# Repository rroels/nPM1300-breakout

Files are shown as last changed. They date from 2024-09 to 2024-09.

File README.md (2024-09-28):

# Nordic nPM1300 Breakout Board

> [!WARNING]
> The information and material (code, designs, files, ...) are provided "AS IS". We make no representation or warranty of any kind, express or implied, regarding the accuracy, adequacy, validity, reliability, availability, or completeness of any information or material. Use this at your own risk.

> [!WARNING]
> At the time of writing this PCB has not even been produced yet, and as such, it has not even been tested yet! Once it has been properly tested, I will confirm that everything works as expected.

## Introduction

This is a breakout board for the Nordic nPM1300 Power Management IC.

[https://www.nordicsemi.com/Products/nPM1300](https://www.nordicsemi.com/Products/nPM1300)

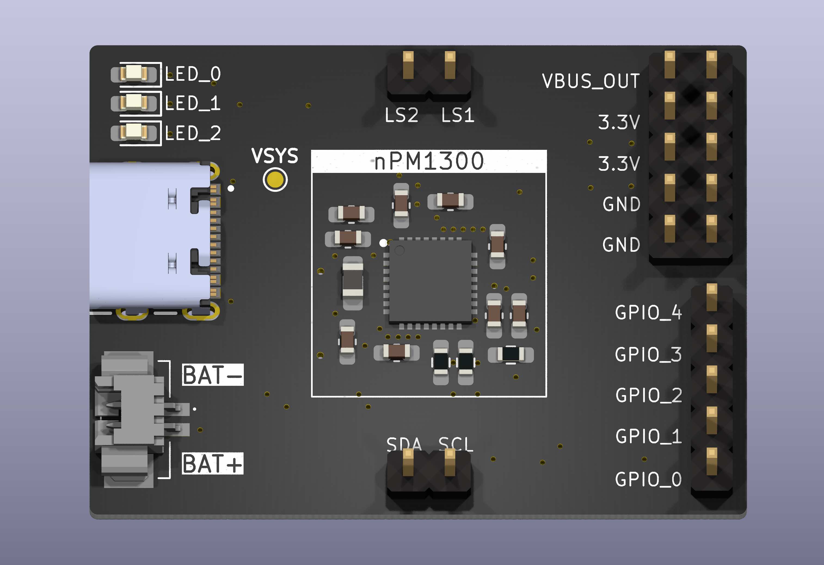
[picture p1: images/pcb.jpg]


## Change Log

* v1.0
  * Initial design 

## Design Considerations

In this design, the nPM1300 is configured like this:

* BUCK1 disabled
* BUCK2 enabled, for converting battery or USB input to 3.3V
* 2 load switches at 3.3V (LS1 and LS2)
* no LDO 
* 3 LEDs
* I2C interface

## Schematics 

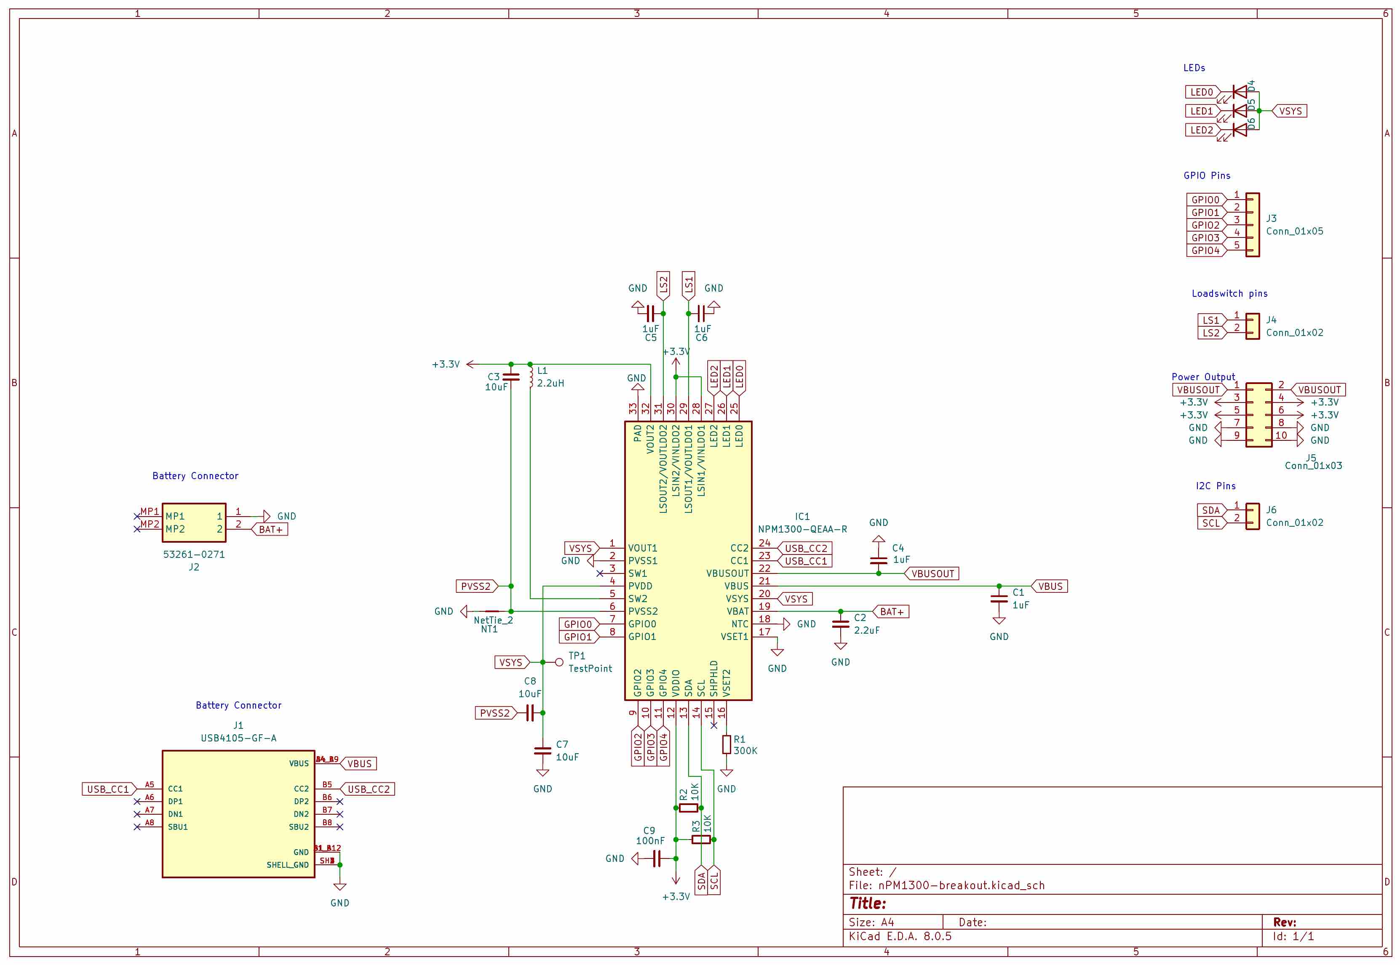
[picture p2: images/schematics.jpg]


## How to Obtain the Physical PCB



The Gerber file is in this repository (`kicad/gerbers/nPM1300-breakout.zip`). Simply upload this file a PCB manufacturer of your choice (JLPCB, PCBWay, ...), and you they will make it for you for as low as \$5 for 5 pieces (with the cheapest shipping option, which can take a few weeks).

For JLCPCB, select the order number option where they will replace "JLCJLCJLCJLC" on the board with the actual order number.

> [!WARNING]
> Note that will still have to solder the components onto the PCB yourself!

## How to Edit Design

Everything you need to edit this design in KiCad 8 is included in the repository.

However, this project uses symbols, footprints and 3D models from [Component Search Engine](https://componentsearchengine.com/). Their license allows us to do pretty much whatever we want with them, except redistributing them. For this reason I can't include them in this repository.

If you would like to edit the design yourself, you will need to download the following component libraries from [https://componentsearchengine.com/](https://componentsearchengine.com/) (it's free!):

* [https://componentsearchengine.com/part-view/NPM1300-QEAA-R/Nordic%20Semiconductor](https://componentsearchengine.com/part-view/NPM1300-QEAA-R/Nordic%20Semiconductor)
* [https://componentsearchengine.com/part-view/53261-0271/Molex](https://componentsearchengine.com/part-view/53261-0271/Molex)

You will also need this from SnapEDA:

* [https://www.snapeda.com/parts/21296912/TE%20Connectivity/view-part/?ref=te_in&t=USB4105-GF-A&con_ref=None](https://www.snapeda.com/parts/21296912/TE%20Connectivity/view-part/?ref=te_in&t=USB4105-GF-A&con_ref=None)

From the downloaded zip files, move the content of the `KiCad` and `3D` subfolders into the project structure, so that the end-result looks like this:

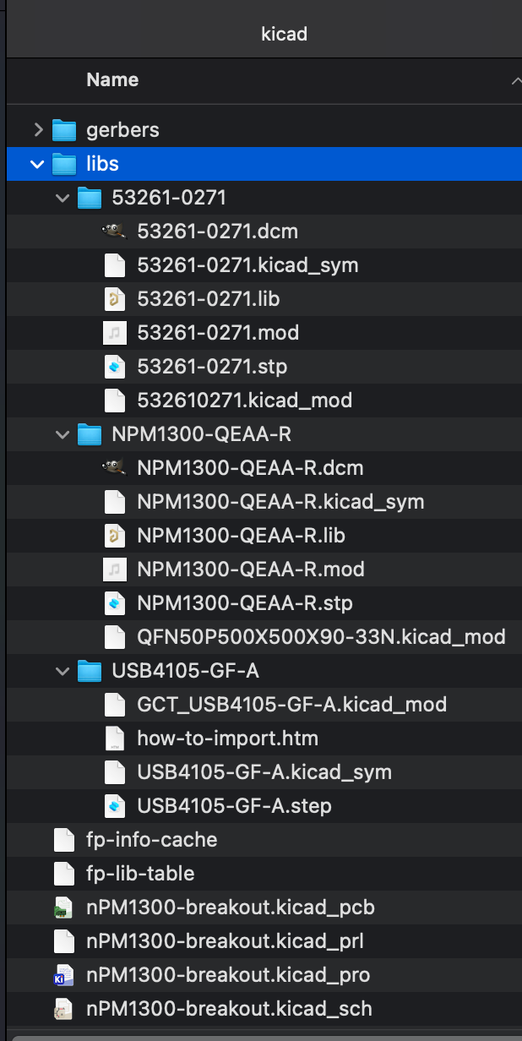
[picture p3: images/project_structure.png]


The KiCad project is configured to look for these files in these locations, using relative paths, so no changes to the project itself are required.	

## Sources

* [https://www.nordicsemi.com/Products/nPM1300](https://www.nordicsemi.com/Products/nPM1300)
* [https://docs.nordicsemi.com/category/npm1300-category](https://docs.nordicsemi.com/category/npm1300-category)

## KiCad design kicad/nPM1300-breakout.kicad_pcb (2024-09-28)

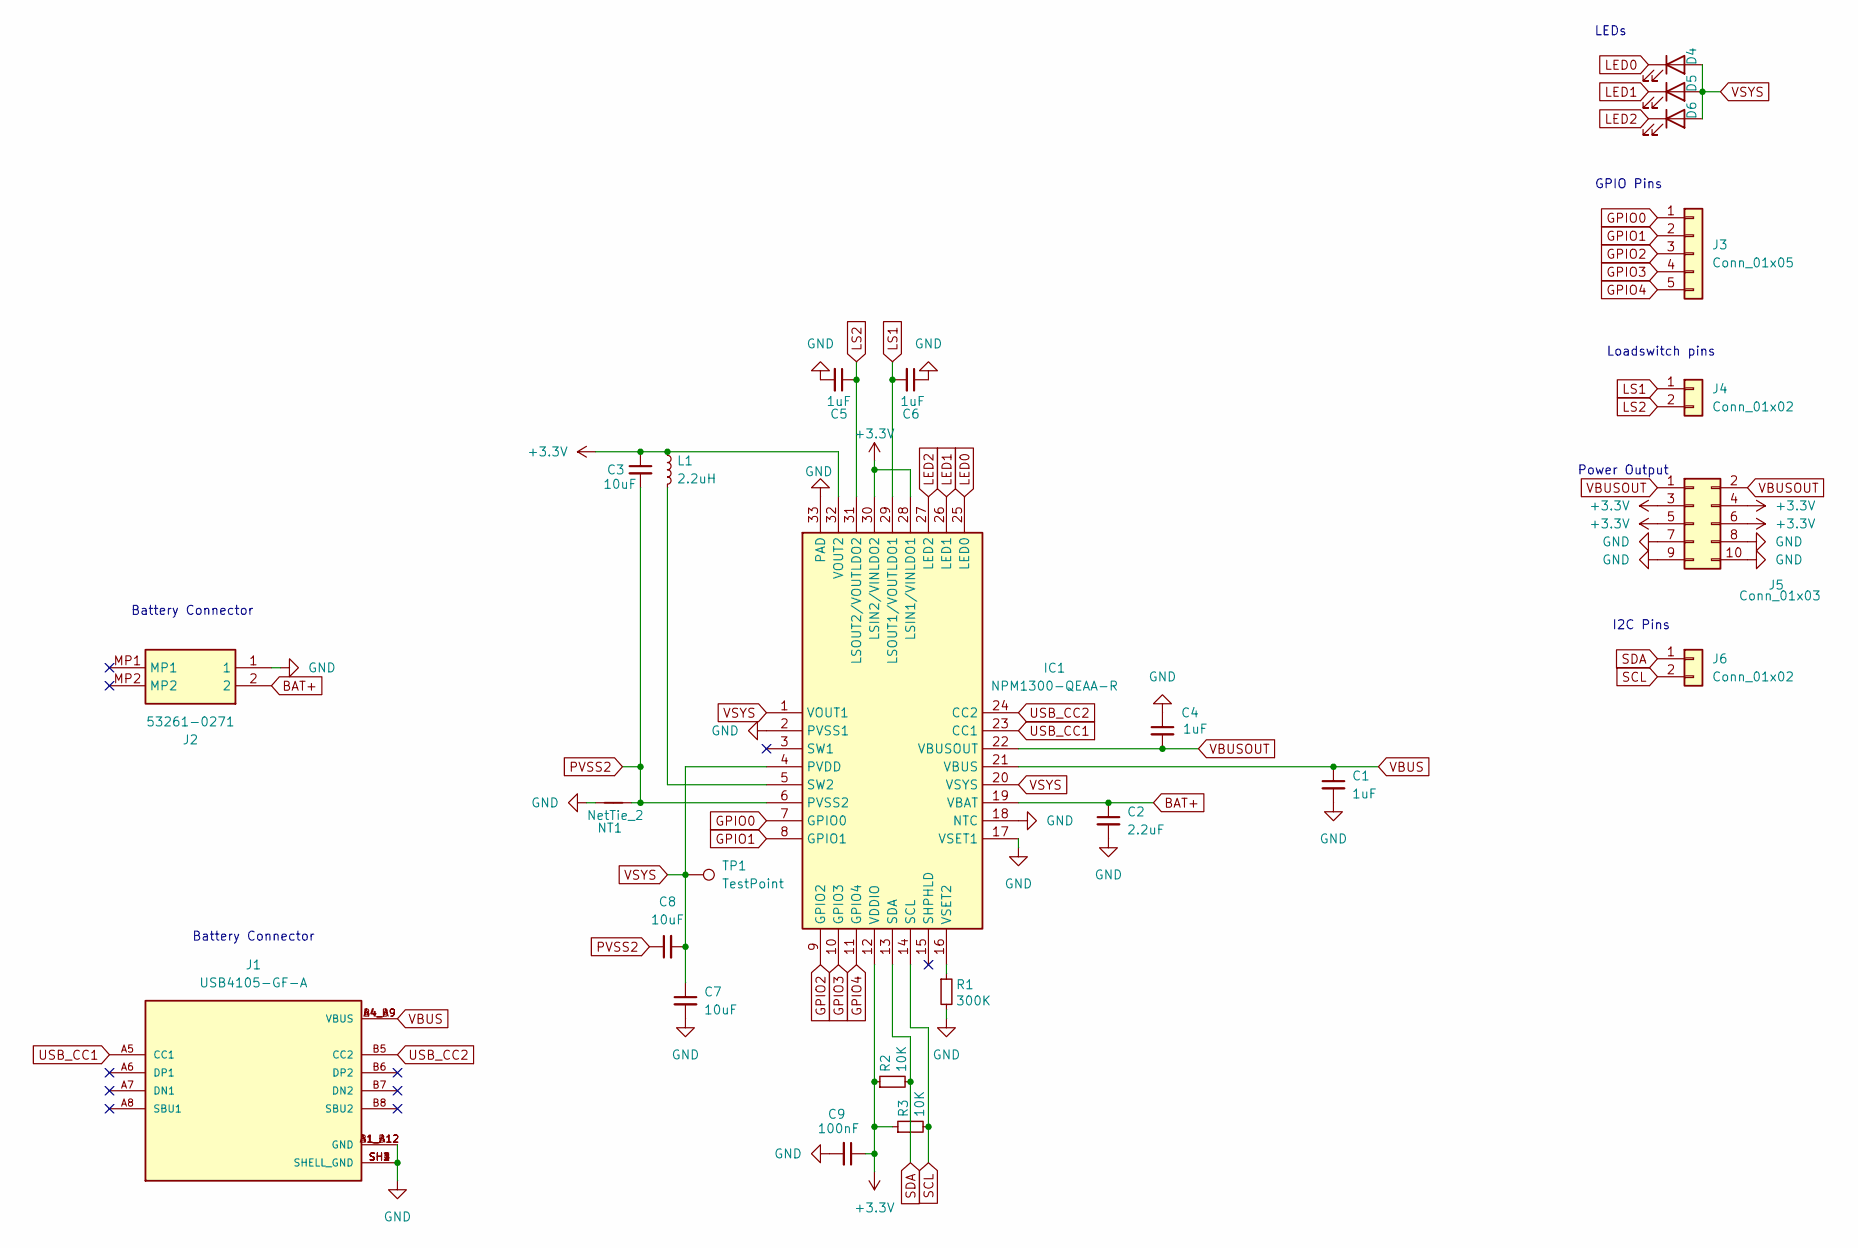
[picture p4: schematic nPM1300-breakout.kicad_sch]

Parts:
C1, C4, C5, C6: 1uF; C_0603_1608Metric_Pad1.08x0.95mm_HandSolder
C2: 2.2uF; C_0603_1608Metric_Pad1.08x0.95mm_HandSolder
C3, C7, C8: 10uF; C_0603_1608Metric_Pad1.08x0.95mm_HandSolder
C9: 100nF; C_0603_1608Metric_Pad1.08x0.95mm_HandSolder
D4, D5, D6: LED; LED_0603_1608Metric_Pad1.05x0.95mm_HandSolder
IC1: NPM1300-QEAA-R; QFN50P500X500X90-33N; Manufacturer_Part_Number NPM1300-QEAA-R; Mouser Part Number 949-NPM1300-QEAA-R
J1: USB4105-GF-A; GCT_USB4105-GF-A; PARTREV B4
J2: 53261-0271; 532610271; Manufacturer_Part_Number 53261-0271; Mouser Part Number 538-53261-0271
J3: Conn_01x05; PinHeader_1x05_P2.54mm_Vertical
J4, J6: Conn_01x02; PinHeader_1x02_P2.54mm_Vertical
J5: Conn_01x03; PinHeader_2x05_P2.54mm_Vertical
L1: 2.2uH; L_0805_2012Metric_Pad1.05x1.20mm_HandSolder
NT1: NetTie_2; NetTie-2_SMD_Pad0.5mm
R1: 300K; R_0603_1608Metric_Pad0.98x0.95mm_HandSolder
R2, R3: 10K; R_0603_1608Metric_Pad0.98x0.95mm_HandSolder
TP1: TestPoint; TestPoint_Pad_D1.0mm

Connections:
+3.3V: C3.1, C9.1, IC1.12 (VDDIO), IC1.28 (LSIN1/VINLDO1), IC1.30 (LSIN2/VINLDO2), IC1.32 (VOUT2), J5.3, J5.4, J5.5, J5.6, L1.1, R2.1, R3.1
BAT+: C2.1, IC1.19 (VBAT), J2.2
GND: C1.2, C2.2, C4.1, C5.2, C6.1, C7.2, C9.2, IC1.2 (PVSS1), IC1.17 (VSET1), IC1.18 (NTC), IC1.33 (PAD), J1.A1_B12 (GND), J1.B1_A12 (GND), J1.SH1 (SHELL_GND), J1.SH2 (SHELL_GND), J1.SH3 (SHELL_GND), J1.SH4 (SHELL_GND), J2.1, J5.7, J5.8, J5.9, J5.10, NT1.1, R1.2
GPIO0: IC1.7 (GPIO0), J3.1
GPIO1: IC1.8 (GPIO1), J3.2
GPIO2: IC1.9 (GPIO2), J3.3
GPIO3: IC1.10 (GPIO3), J3.4
GPIO4: IC1.11 (GPIO4), J3.5
LED0: D4.1 (K), IC1.25 (LED0)
LED1: D5.1 (K), IC1.26 (LED1)
LED2: D6.1 (K), IC1.27 (LED2)
LS1: C6.2, IC1.29 (LSOUT1/VOUTLDO1), J4.1
LS2: C5.1, IC1.31 (LSOUT2/VOUTLDO2), J4.2
unnamed: IC1.5 (SW2), L1.2
unnamed: IC1.16 (VSET2), R1.1
PVSS2: C3.2, C8.1, IC1.6 (PVSS2), NT1.2
SCL: IC1.14 (SCL), J6.2, R3.2
SDA: IC1.13 (SDA), J6.1, R2.2
USB_CC1: IC1.23 (CC1), J1.A5 (CC1)
USB_CC2: IC1.24 (CC2), J1.B5 (CC2)
VBUS: C1.1, IC1.21 (VBUS), J1.A4_B9 (VBUS), J1.B4_A9 (VBUS)
VBUSOUT: C4.2, IC1.22 (VBUSOUT), J5.1, J5.2
VSYS: C7.1, C8.2, D4.2 (A), D5.2 (A), D6.2 (A), IC1.1 (VOUT1), IC1.4 (PVDD), IC1.20 (VSYS), TP1.1; also elsewhere on the board

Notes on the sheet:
Battery Connector
GPIO Pins
Power Output
LEDs
I2C Pins
Loadswitch pins

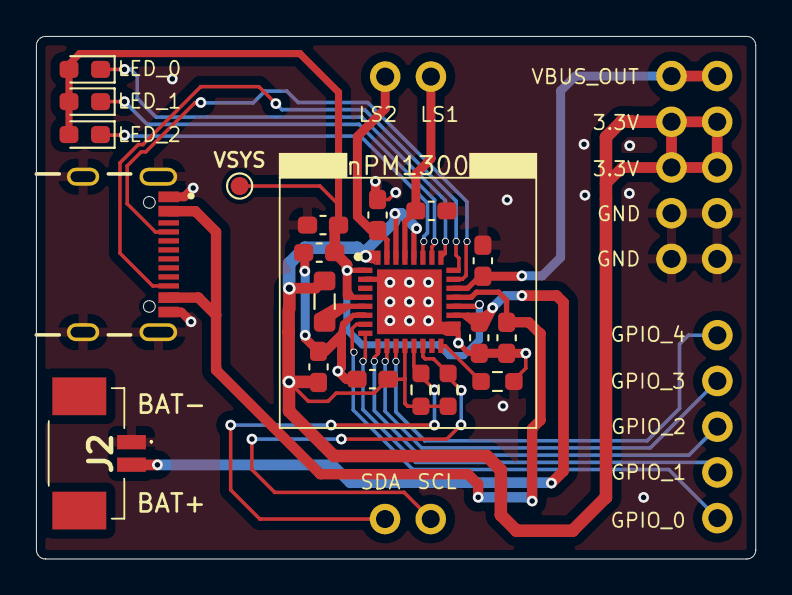
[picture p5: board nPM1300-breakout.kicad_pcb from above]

Board: 2 copper layers, 40.0 x 29.0 mm, 25 parts (0 on the bottom side), 23 nets.

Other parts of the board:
VSYS: TestPoint; TestPoint_Pad_D1.0mm

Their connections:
VSYS: VSYS.1; also elsewhere on the board
